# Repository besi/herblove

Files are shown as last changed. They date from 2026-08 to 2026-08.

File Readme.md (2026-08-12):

Herblove
========

Connect a PET bottle to a water drip adapter and keep your herbs happy.

## Features

- Control a 12V valve
- Battery powered with solar charging
- Measure temperature and humidity
- Log data onto an SD card
- Read a floating sensor
- Two buttons
- Onboard Neopixel

## Pinout

| Pin | Function |
|-----|---|
| 2 | Enable 12V  |
| 10  | I2C SCL |
| 8 | I2C SDA |
| 1 | SPI MISO |
| 4 | SPI MOSI |
| 0 | SPI CLK |
| 5 | SPI CS |
| 6 | Buttons ADC |
| 3 | ADC Battery |
| 7 | Neopixel |

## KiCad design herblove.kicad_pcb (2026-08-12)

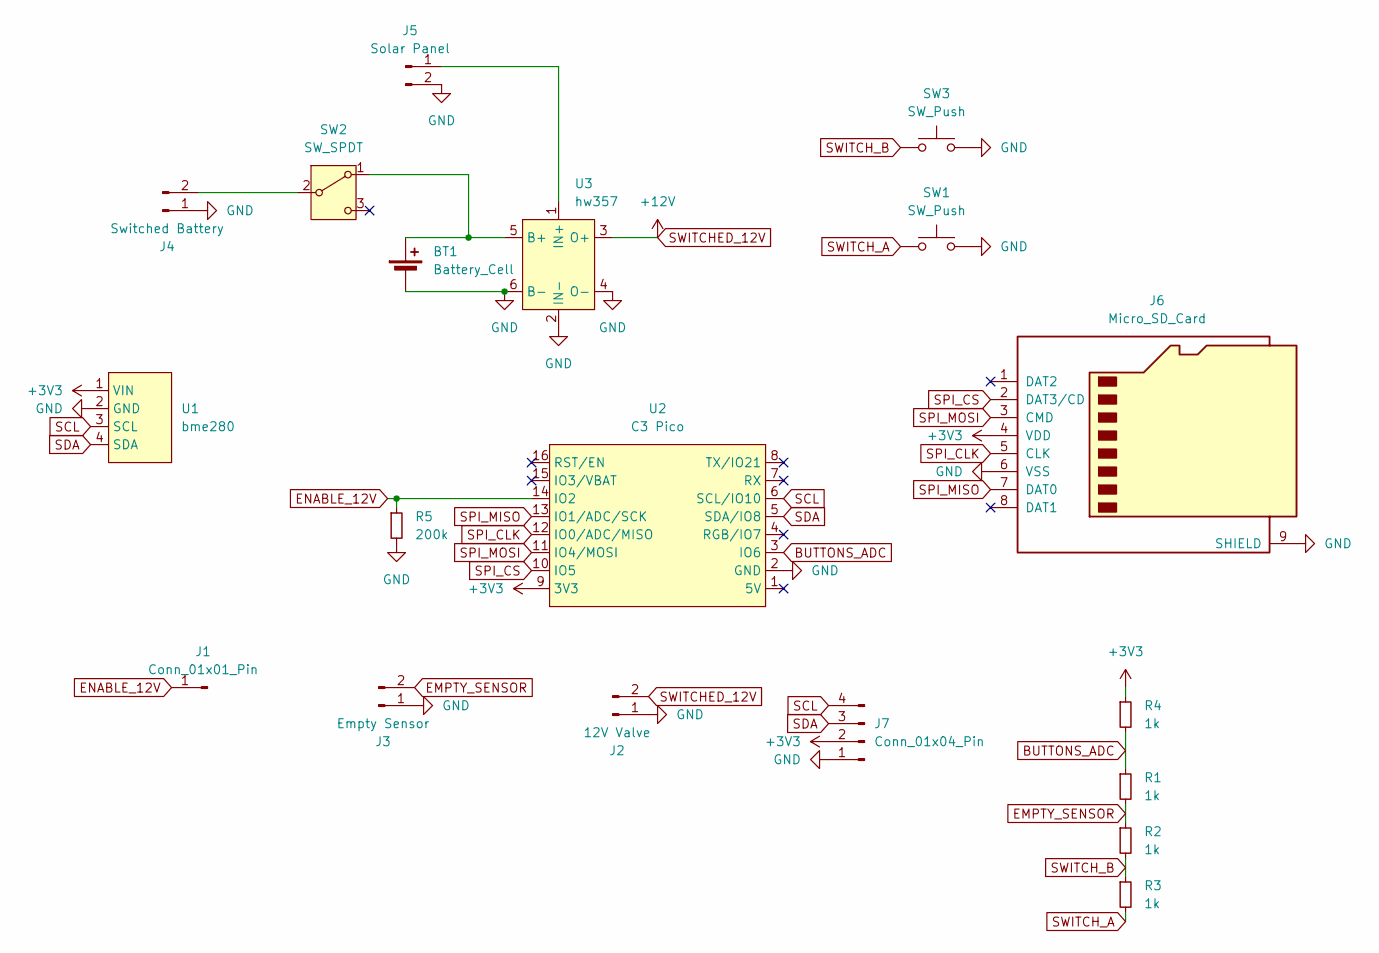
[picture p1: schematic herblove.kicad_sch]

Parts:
BT1: Battery_Cell; JST_PH_B2B-PH-K_1x02_P2.00mm_Vertical
J1: Conn_01x01_Pin; PinHeader_1x01_P2.54mm_Vertical
J2: 12V Valve; PinHeader_1x02_P2.54mm_Vertical
J3: Empty Sensor; PinHeader_1x02_P2.54mm_Vertical
J4: Switched Battery; JST_PH_B2B-PH-K_1x02_P2.00mm_Vertical
J5: Solar Panel; JST_PH_B2B-PH-K_1x02_P2.00mm_Vertical
J6: Micro_SD_Card; sd-card
J7: Conn_01x04_Pin; PinHeader_1x04_P2.54mm_Vertical
R1, R2, R3, R4: 1k; R_Axial_DIN0207_L6.3mm_D2.5mm_P7.62mm_Horizontal
R5: 200k; R_Axial_DIN0207_L6.3mm_D2.5mm_P7.62mm_Horizontal
SW1, SW3: SW_Push; pts636
SW2: SW_SPDT; as12ap
U1: bme280
U2: C3 Pico; c3-pico
U3: hw357

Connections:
+3V3: J6.4 (VDD), J7.2, R4.1, U1.1 (VIN), U2.9 (3V3)
BUTTONS_ADC: R1.1, R4.2, U2.3 (IO6)
EMPTY_SENSOR: J3.2, R1.2, R2.1
ENABLE_12V: J1.1, R5.1, U2.14 (IO2)
GND: BT1.2 (-), J2.1, J3.1, J4.1, J5.2, J6.6 (VSS), J6.9 (SHIELD), J7.1, R5.2, SW1.2, SW3.2, U1.2 (GND), U2.2 (GND), U3.2 (IN-), U3.4 (O-), U3.6 (B-)
unnamed: BT1.1 (+), SW2.1 (A), U3.5 (B+)
unnamed: J4.2, SW2.2 (B)
unnamed: J5.1, U3.1 (IN+)
SCL: J7.4, U1.3 (SCL), U2.6 (SCL/IO10)
SDA: J7.3, U1.4 (SDA), U2.5 (SDA/IO8)
SPI_CLK: J6.5 (CLK), U2.12 (IO0/ADC/MISO)
SPI_CS: J6.2 (DAT3/CD), U2.10 (IO5)
SPI_MISO: J6.7 (DAT0), U2.13 (IO1/ADC/SCK)
SPI_MOSI: J6.3 (CMD), U2.11 (IO4/MOSI)
SWITCHED_12V: J2.2, U3.3 (O+)
SWITCH_A: R3.2, SW1.1
SWITCH_B: R2.2, R3.1, SW3.1

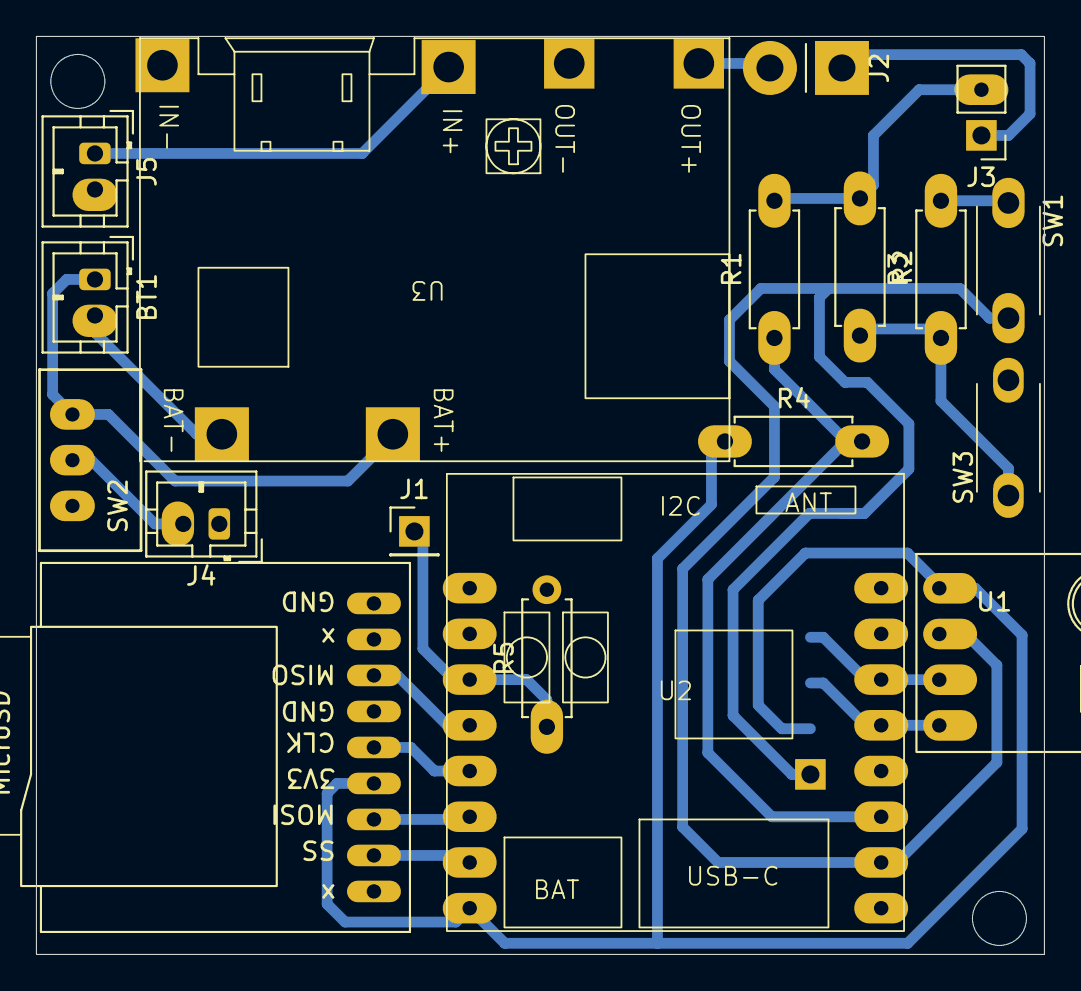
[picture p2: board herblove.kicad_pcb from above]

Board: 2 copper layers, 56.0 x 51.0 mm, 19 parts (1 on the bottom side), 17 nets.

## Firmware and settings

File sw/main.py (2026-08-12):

from machine import Pin
from neopixel import NeoPixel
import time

np = NeoPixel(Pin(7),1)

np.fill((10,10,10)); np.write()

valve = Pin(2, Pin.OUT)

while True:
  
    np.fill((10,0,0));np.write()
    valve.on()
    time.sleep(3)
      
    np.fill((0,10,0));np.write()
    valve.off()
    time.sleep(3)

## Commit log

2026-08-11 Add initial components and libraries
    [herblove.kicad_pcb, herblove.kicad_sch]
2026-08-11 Add final components
    [herblove.kicad_pcb, herblove.kicad_sch]
2026-08-11 Finalise routing
    [herblove.kicad_pcb, herblove.kicad_sch]
2026-08-11 Update hw357 3d model and prepare for milling
    [herblove.kicad_pcb]
2026-08-12 Ground all the negative terminals of the battery step up converter
    [herblove.kicad_pcb, herblove.kicad_sch]
2026-08-12 Add a weak pull down for the enable pin of the step up converter
    [herblove.kicad_pcb, herblove.kicad_sch]
2026-08-12 Fix polarity of the solar plug
    [herblove.kicad_pcb, herblove.kicad_sch]
2026-08-12 Add simple test program enabling and disabling the valve in 3 second intervals
